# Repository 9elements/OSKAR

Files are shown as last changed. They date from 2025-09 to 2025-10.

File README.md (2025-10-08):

# Open Source Keyboard Appliance powered by Rust

OSKAR is a firmware for the Raspberry Pi Pico it combines the 9elements picoprog project and additional Hid code into a firmware for our multi-feature Makro-Keypad.
## Prerequisites

Before you can compile and use OSKAR, you need to install the following dependencies:

- Rust and Cargo: Follow the instructions on the [official Rust website](https://www.rust-lang.org/tools/install) to install Rust and Cargo.
- Install flip-link and elf2uf2

```sh
# Only Linux
sudo apt install build-essential libudev-dev pkg-config

# All systems
cargo install flip-link elf2uf2-rs
```

## Compiling the Firmware

To compile the firmware, follow these steps:

1. Clone the repository:

```sh
git clone https://github.com/9elements/OSKAR.git
cd OSKAR
```

Build the firmware:

```sh
cargo run --release
```

3. The compiled binary will be located in the `target/thumbv6m-none-eabi/release` directory.

## Flashing the Firmware

To flash the firmware onto the Raspberry Pi Pico, follow these steps:

1. Connect the Raspberry Pi Pico to your computer while holding the BOOTSEL button. This will put the Pico into USB mass storage mode.

2. Copy the UF2 file to the Pico:

```sh
# Linux
cp target/thumbv6m-none-eabi/release/oskar.uf2 /path/to/pi/volume

# macOS
cp target/thumbv6m-none-eabi/release/picoprog.uf2 /Volumes/RPI-RP2/
```

3. The Pico will automatically reboot and start running the new firmware.

## Usage

### Modes

The Device features a 3-position selection switch on its left side. When the switch is moved all the way to the back it simply acts ats the picoprog featuring SPI and UART capabillities (Green LED). Moved all the way to the fromt it acts as Macro Keyboard (Red LED). With the switch in the middle position the device combines Both features at once (purple led).

### Makro Keyboard

The standard firmware of the Keyboard hase the encoder configured as volume knob with mute on press.
The keys 1-3 (from left to right) are configured as o s and f (for open source firmware).

At the top of the file `src/hid.rs` there is a constant struct called ```KEYLAYOUT```.

```rust
const KEYLAYOUT:KeyLayout = KeyLayout {
    encoder_left: KeyType::Media(MediaKey::VolumeDecrement),
    encoder_right: KeyType::Media(MediaKey::VolumeIncrement),
    encoder_button: KeyType::Media(MediaKey::Mute),
    key1: KeyType::Keycode(KeyboardUsage::KeyboardOo),
    key2: KeyType::Keycode(KeyboardUsage::KeyboardSs),
    key3: KeyType::Keycode(KeyboardUsage::KeyboardFf),
};
```

The struct holds the current configuration of the Keyboard, each key can be configured to any keycode of the enum ```KeyType``` located in `src/hid_codes.rs`
for example:

```rust
const KEYLAYOUT:KeyLayout = KeyLayout {
    encoder_left: KeyType::Media(MediaKey::VolumeDecrement),
    encoder_right: KeyType::Media(MediaKey::VolumeIncrement),
    encoder_button: KeyType::Media(MediaKey::Mute),
    key1: KeyType::Keycode(KeyboardUsage::KeyboardF10),
    key2: KeyType::Keycode(KeyboardUsage::KeyboardF11),
    key3: KeyType::Keycode(KeyboardUsage::KeyboardF12),
};
```

Wich could then be used to be configured as hotkeys in your operating system.

### Serial (picocom or combined mode)

Once the firmware is running, you can use any terminal program to communicate with the UART and SPI peripherals via USB. The device will appear as a USB CDC (Communications Device Class) device. Currently `/dev/ttyACM0` (macOS: `/dev/tty.usbmodemOSFC20241`) is a debug console that prints information about the picos current operation.

### UART Communication (picocom or combined mode)

To communicate with the UART peripheral, open the corresponding serial port (e.g., `/dev/ttyACM1` on Linux, `/dev/tty.usbmodemOSFC20243` on macOS) with your terminal program. For now the Baud is fixed at 115200 but can be changed in code. Dynamic reconfiguration is still planned.

### Using Flashrom or Flashprog (picocom or combined mode)

To interact with the Raspberry Pi Pico in for reading and writing SPI flash chips, you can use tools like `flashrom` or `flashprog`. These tools support the `serprog` protocol, which allows communication over a serial interface.

1. Install `flashrom` or `flashprog` e.g.:

```sh
# Debian or Debian-based Linux distributions
sudo apt-get install flashrom

# macOS with Homebrew
brew install flashrom
```

2. Use the following command to read from the SPI flash chip:

```sh
flashrom -p serprog:dev=/dev/ttyACM2 -r backup.bin
```

This command reads the contents of the SPI flash chip and saves it to `backup.bin`.

3. Use the following command to write to the SPI flash chip:

```sh
flashrom -p serprog:dev=/dev/ttyACM2 -w firmware.bin
```

This command writes the contents of `firmware.bin` to the SPI flash chip.

Make sure to replace `/dev/ttyACM2` with the correct serial port if your device is connected to a different port or if you're on a different operating system (on macOS it will be `/dev/tty.usbmodemOSFC20245`).

## License

This project is licensed under the Apache 2.0 License. See the [LICENSE](LICENSE) file for details.

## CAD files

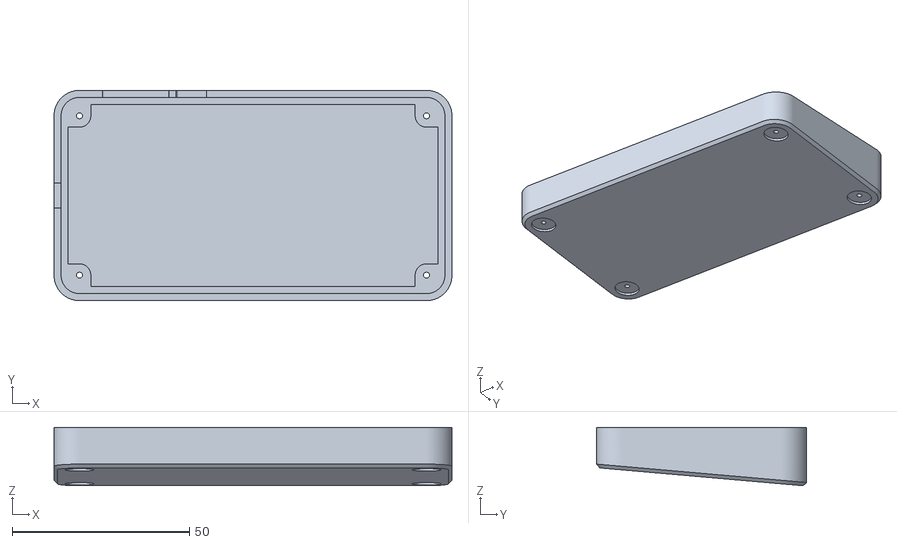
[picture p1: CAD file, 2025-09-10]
hardware/case/CaseBase.stl
112.4 x 59.4 x 16.5

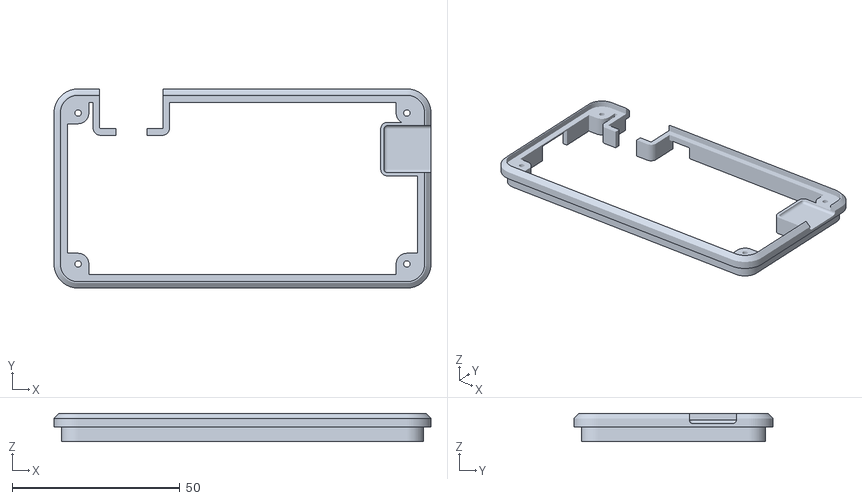
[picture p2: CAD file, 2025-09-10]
hardware/case/CaseTop.stl
112.4 x 59.4 x 8.40

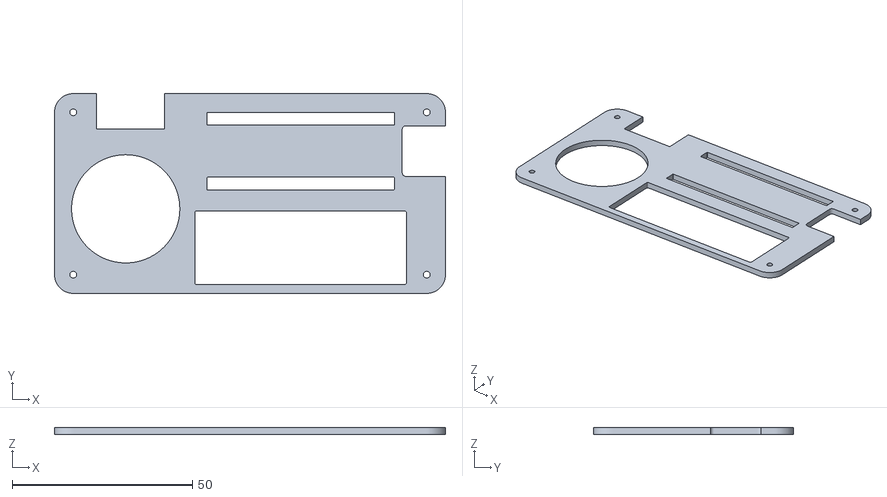
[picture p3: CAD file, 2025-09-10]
hardware/case/TopPlate.stl
108.4 x 55.4 x 2.00

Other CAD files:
hardware/case/TopPlate.dxf

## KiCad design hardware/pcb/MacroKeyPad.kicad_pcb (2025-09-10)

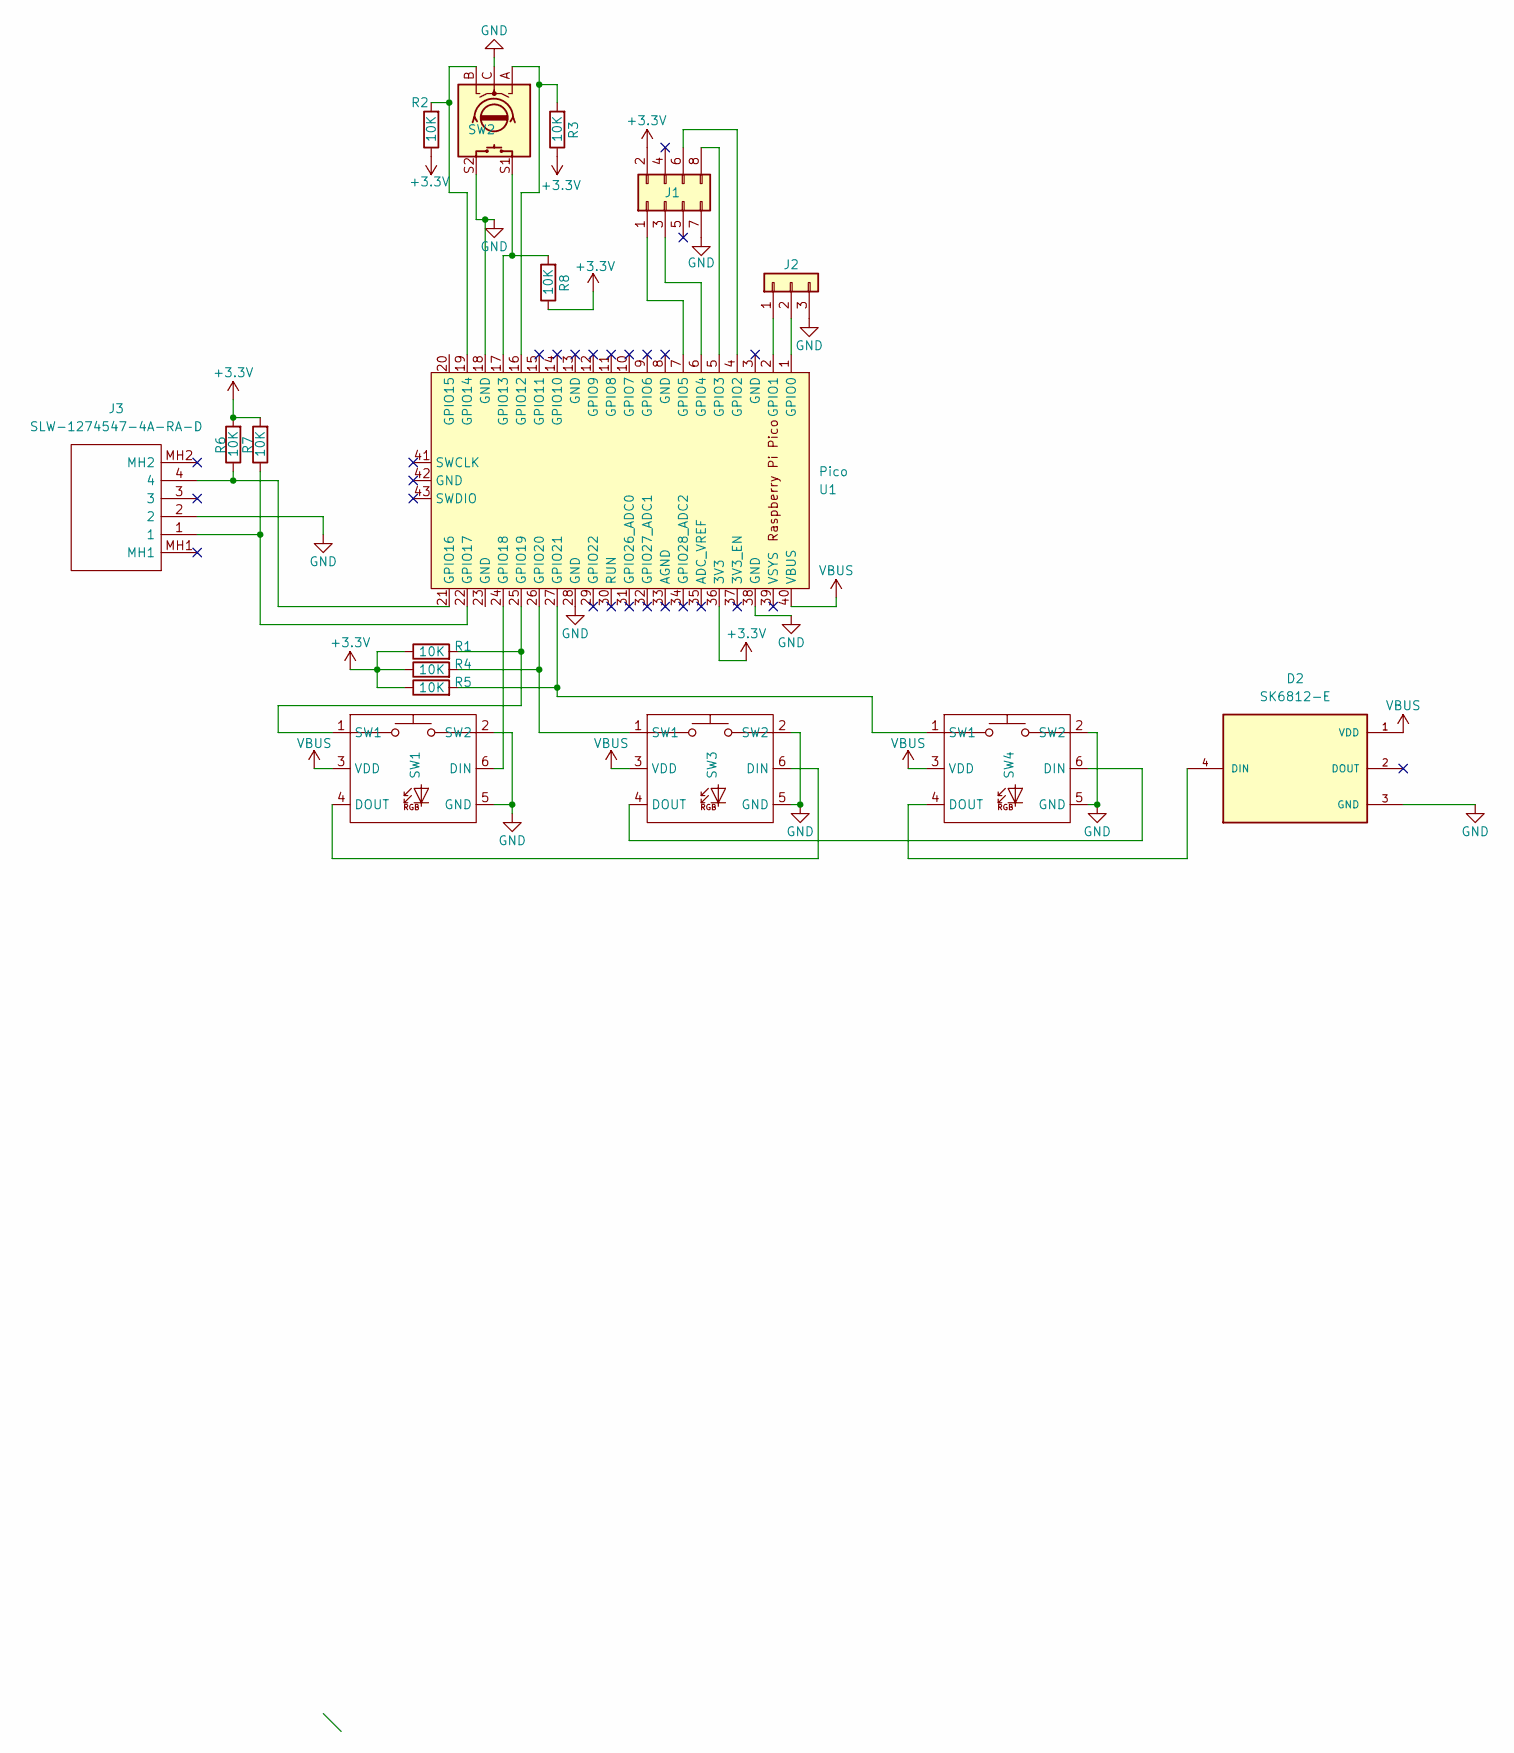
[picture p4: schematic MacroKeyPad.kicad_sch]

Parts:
D2: SK6812-E; LED_SK6812-E; PARTREV 2
J1: Conn_02x04_Odd_Even; IDC-Header_2x04_P2.54mm_Horizontal
J2: Conn_01x03; PinHeader_1x03_P2.54mm_Horizontal
J3: SLW-1274547-4A-RA-D; SLW12745474ARAD; Mouser Part Number 179-SLW12745474ARAD
R1, R2, R3, R4, R5, R6, R7, R8: 10K; R_0805_2012Metric_Pad1.20x1.40mm_HandSolder
SW1, SW3, SW4: Cherry_MX_SK6812_MINI_E
SW2: RotaryEncoder_Switch; RotaryEncoder_Alps_EC11E-Switch_Vertical_H20mm
U1: Pico; RPi_Pico_SMD_HEADER

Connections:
+3.3V: J1.2, R1.1, R2.1, R3.1, R4.1, R5.1, R6.2, R7.2, R8.1, U1.36 (3V3)
GND: D2.3 (GND), J1.7, J2.3, J3.2, SW1.2 (SW2), SW1.5 (GND), SW2.C, SW2.S2, SW3.2 (SW2), SW3.5 (GND), SW4.2 (SW2), SW4.5 (GND), U1.18 (GND), U1.28 (GND), U1.38 (GND)
unnamed: D2.4 (DIN), SW4.4 (DOUT)
unnamed: J1.1, U1.7 (GPIO5)
unnamed: J1.3, U1.6 (GPIO4)
unnamed: J1.6, U1.4 (GPIO2)
unnamed: J1.8, U1.5 (GPIO3)
unnamed: J2.1, U1.2 (GPIO1)
unnamed: J2.2, U1.1 (GPIO0)
unnamed: SW1.6 (DIN), U1.24 (GPIO18)
unnamed: SW1.4 (DOUT), SW3.6 (DIN)
unnamed: R1.2, SW1.1 (SW1), U1.25 (GPIO19)
unnamed: SW3.4 (DOUT), SW4.6 (DIN)
unnamed: R4.2, SW3.1 (SW1), U1.26 (GPIO20)
unnamed: R5.2, SW4.1 (SW1), U1.27 (GPIO21)
unnamed: R3.2, SW2.A, U1.16 (GPIO12)
unnamed: R8.2, SW2.S1, U1.17 (GPIO13)
unnamed: R2.2, SW2.B, U1.19 (GPIO14)
unnamed: J3.4, R6.1, U1.21 (GPIO16)
unnamed: J3.1, R7.1, U1.22 (GPIO17)
VBUS: D2.1 (VDD), SW1.3 (VDD), SW3.3 (VDD), SW4.3 (VDD), U1.40 (VBUS)

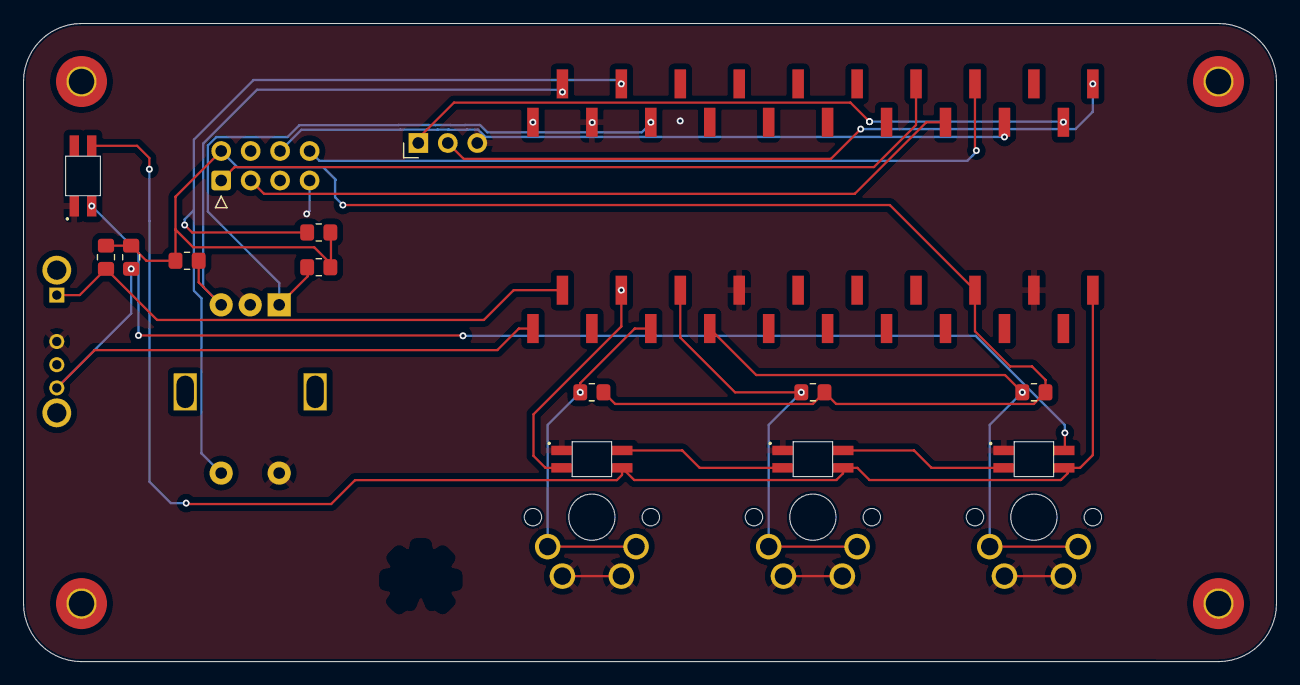
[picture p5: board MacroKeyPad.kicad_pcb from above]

Board: 2 copper layers, 108.0 x 55.0 mm, 17 parts (0 on the bottom side), 21 nets.

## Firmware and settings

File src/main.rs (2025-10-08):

#![no_std]
#![no_main]
#![allow(async_fn_in_trait)]
#![allow(incomplete_features)]
#![feature(impl_trait_in_assoc_type)]
#![feature(type_alias_impl_trait)]

use assign_resources::assign_resources;
use core::panic::PanicInfo;
use cortex_m::peripheral::SCB;
use defmt_rtt as _;
use embassy_executor::Spawner;
use embassy_futures::select::select_array;
use embassy_rp::bind_interrupts;
use embassy_rp::flash::{Async, Flash};
use embassy_rp::gpio::{Input, Level, Output, Pull};
use embassy_rp::peripherals::{self, PIO0, SPI0, USB};
use embassy_rp::pio::InterruptHandler as PIOInterruptHandler;
use embassy_rp::spi::{Config as SpiConfig, Spi};
use embassy_rp::usb::{Driver, InterruptHandler as USBInterruptHandler};
use embassy_rp::watchdog::Watchdog;
use embassy_usb::class::cdc_acm::{CdcAcmClass, State as CdcAcmState};
use embassy_usb::class::hid::{HidReaderWriter, State as Hid_State};
use usbd_hid::descriptor::{KeyboardReport, MediaKeyboardReport, SerializedDescriptor};

use embassy_usb::{Config as UsbConfig, UsbDevice};
use heapless::String;
use static_cell::StaticCell;
use ufmt::uwrite;

mod hid;
mod layouts;
mod led;
mod uart;
bind_interrupts!(struct Irqs {
    USBCTRL_IRQ => USBInterruptHandler<USB>;
    PIO0_IRQ_0 => PIOInterruptHandler<PIO0>;
});

assign_resources! {
    uart: UartResources{
        peripheral: PIO0,
        tx: PIN_0,
        rx: PIN_1,
    }
    spi: SpiResources{
        peripheral: SPI0,
        clk: PIN_2,
        mosi: PIN_3,
        mosi_dma: DMA_CH2,
        miso: PIN_4,
        miso_dma: DMA_CH3,
        cs: PIN_5,
        led: PIN_25,
    }

    hid: ButtonResources{
        key1: PIN_19,
        key2: PIN_20,
        key3: PIN_21,
        encoder_button: PIN_13,
    }

    encoder: EncoderResources{
        encoder_right: PIN_14,
        encoder_left: PIN_12,
    }

    led: LedResources{
        peripheral: PIO1,
        led_gpio: PIN_18,
        led_dma: DMA_CH0,
    }

    selector_switch: ModeSwitchRessources{
        selector_kb: PIN_16,
        selector_picocprog: PIN_17,
    }
}

#[derive(Clone, Copy, Debug)]
pub enum DeviceMode {
    Keyboard,
    Picoprog,
    Universal,
}

// According to Serial Flasher Protocol Specification - version 1
const FLASH_SIZE: usize = 2 * 1024 * 1024;



#[embassy_executor::main]
async fn main(spawner: Spawner) {
    let p: embassy_rp::Peripherals = embassy_rp::init(Default::default());
    let r: AssignedResources = split_resources!(p);
    let driver = Driver::new(p.USB, Irqs);

    let selector_keyboard: Input<'_> = Input::new(r.selector_switch.selector_kb, Pull::Up);
    let selector_picoprog: Input<'_> = Input::new(r.selector_switch.selector_picocprog, Pull::Up);
    let watchdog = Watchdog::new(p.WATCHDOG);

    let mode: DeviceMode = if selector_keyboard.get_level() == Level::Low {
        defmt::info!("keyboard mode");
        DeviceMode::Keyboard
    } else if selector_picoprog.get_level() == Level::Low {
        defmt::info!("picoprog mode");
        DeviceMode::Picoprog
    } else {
        defmt::info!("neutral mode");
        DeviceMode::Universal
    };

    let mut flash = Flash::<_, Async, FLASH_SIZE>::new(p.FLASH, p.DMA_CH4);
    let mut uid: [u8; 8] = [0; 8];
    flash.blocking_unique_id(&mut uid).unwrap_or_default();

    static UID_STR: StaticCell<String<16>> = StaticCell::new();
    let uid_str = UID_STR.init(String::<16>::new());
    for byte in uid.iter() {
        uwrite!(uid_str, "{:02X}", *byte).unwrap_or_default();
    }

    let config = {
        let mut config = UsbConfig::new(0x1ced, 0xc0fe);
        config.manufacturer = Some("9elements");
        config.product = Some("oskar");
        config.serial_number = Some(uid_str.as_str());
        config.max_power = 100;
        config.max_packet_size_0 = 64;

        // Required for windows compatibility.
        // https://developer.nordicsemi.com/nRF_Connect_SDK/doc/1.9.1/kconfig/CONFIG_CDC_ACM_IAD.html#help
        config.device_class = 0xEF;
        config.device_sub_class = 0x02;
        config.device_protocol = 0x01;
        config.composite_with_iads = true;
        config
    };

    let mut builder: embassy_usb::Builder<'_, Driver<'_, USB>> = {
        static CONFIG_DESCRIPTOR: StaticCell<[u8; 256]> = StaticCell::new();
        static BOS_DESCRIPTOR: StaticCell<[u8; 256]> = StaticCell::new();
        static CONTROL_BUF: StaticCell<[u8; 64]> = StaticCell::new();
        static MSOS_DESCRIPTOR: StaticCell <[u8; 256]> = StaticCell::new();

        let builder = embassy_usb::Builder::new(
            driver,
            config,
            CONFIG_DESCRIPTOR.init([0; 256]),
            BOS_DESCRIPTOR.init([0; 256]),
            MSOS_DESCRIPTOR.init([0; 256]), // no msos descriptors
            CONTROL_BUF.init([0; 64]),
        );
        builder
    };

    spawner.spawn(led::led_task(r.led, mode)).unwrap();

    if !(matches!(mode, DeviceMode::Keyboard)) {
        let uart_class = {
            static STATE: StaticCell<CdcAcmState> = StaticCell::new();
            let state = STATE.init(CdcAcmState::new());
            CdcAcmClass::new(&mut builder, state, 64)
        };

        let serprog_class = {
            static STATE: StaticCell<CdcAcmState> = StaticCell::new();
            let state = STATE.init(CdcAcmState::new());
            CdcAcmClass::new(&mut builder, state, 64)
        };

        spawner.spawn(uart::uart_task(uart_class, r.uart)).unwrap();
        spawner.spawn(serprog_task(serprog_class, r.spi)).unwrap();
    }

    if !(matches!(mode, DeviceMode::Picoprog)) {
        let keyboard_class: HidReaderWriter<'_, Driver<'_, USB>, 1, 8> = {
            static STATE: StaticCell<Hid_State> = StaticCell::new();
            let state = STATE.init(Hid_State::new());

            let config = embassy_usb::class::hid::Config {
                report_descriptor: KeyboardReport::desc(),
                request_handler: None,
                poll_ms: 60,
                max_packet_size: 64,
            };

            HidReaderWriter::new(&mut builder, state, config)
        };

        let multimedia_class: HidReaderWriter<'_, Driver<'_, USB>, 1, 8> = {
            static STATE: StaticCell<Hid_State> = StaticCell::new();
            let state = STATE.init(Hid_State::new());

            let config = embassy_usb::class::hid::Config {
                report_descriptor: MediaKeyboardReport::desc(),
                request_handler: None,
                poll_ms: 60,
                max_packet_size: 64,
            };

            HidReaderWriter::new(&mut builder, state, config)
        };

        spawner.spawn(hid::hid_task(spawner, keyboard_class, multimedia_class, r.hid, r.encoder)).unwrap();
    }

    let usb = builder.build();
    // We can't really recover here so just unwrap
    spawner.spawn(usb_task(usb)).unwrap();
    spawner
        .spawn(selector_watchdog_task(
            watchdog,
            selector_keyboard,
            selector_picoprog,
        ))
        .unwrap();

    loop {
        embassy_time::Timer::after(embassy_time::Duration::from_secs(1)).await;
    }
}

type CustomUsbDriver = Driver<'static, USB>;
type CustomUsbDevice = UsbDevice<'static, CustomUsbDriver>;

#[embassy_executor::task]
async fn usb_task(mut usb: CustomUsbDevice) -> ! {
    usb.run().await
}

#[embassy_executor::task]
async fn selector_watchdog_task(
    mut watchdog: Watchdog,
    mut selector_keyboard: Input<'static>,
    mut selector_picoprog: Input<'static>,
) {
    let (_, _) = select_array([
        selector_keyboard.wait_for_any_edge(),
        selector_picoprog.wait_for_any_edge(),
    ])
    .await;

    watchdog.trigger_reset();
}

#[embassy_executor::task]
async fn serprog_task(class: CdcAcmClass<'static, CustomUsbDriver>, r: SpiResources) -> ! {
    let mut config = SpiConfig::default();
    config.frequency = 12_000_000; // 12 MHz

    let spi = Spi::new(
        r.peripheral,
        r.clk,
        r.mosi,
        r.miso,
        r.mosi_dma,
        r.miso_dma,
        config,
    );
    let cs = Output::new(r.cs, Level::High);
    let led = Output::new(r.led, Level::Low);

    let set_freq_cb = move |spi: &mut Spi<'_, SPI0, embassy_rp::spi::Async>, freq| {
        spi.set_frequency(freq);
    };

    let serprog = serprog::Serprog::new(spi, cs, led, class, Some(set_freq_cb));
    serprog.run_loop().await
}

#[panic_handler]
fn panic(info: &PanicInfo) -> ! {
    // Print out the panic info
    log::error!("Panic occurred: {:?}", info);

    // Reboot the system
    SCB::sys_reset();
}

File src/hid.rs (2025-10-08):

use crate::{EncoderResources, ButtonResources};
use crate::layouts::{KeyLayout};
use defmt::unreachable;
use defmt_rtt as _;
use embassy_executor::{InterruptExecutor, Spawner};
use embassy_futures::select::select_array;
use embassy_rp::gpio::{Input, Level, Pull};
use embassy_rp::interrupt;
use embassy_rp::interrupt::{InterruptExt, Priority};
use embassy_rp::peripherals::USB;
use embassy_rp::usb::Driver;
use embassy_usb::class::hid::HidReaderWriter;
use usbd_hid::descriptor::*;
use embassy_sync::pubsub::PubSubChannel;
use embassy_sync::blocking_mutex::raw::CriticalSectionRawMutex;
type CustomHid = HidReaderWriter<'static, Driver<'static, USB>, 1, 8>;
static KEY_EVENT_QUEUE: PubSubChannel::<CriticalSectionRawMutex, KeyEvent, 2, 2, 2> = PubSubChannel::new();

#[derive(Clone)]
#[derive(PartialEq)]
enum Key {
    EncoderLeft,
    EncoderRight,
    EncoderButton,
    Key1,
    Key2,
    Key3,
}

#[derive(Clone)]
#[derive(PartialEq)]
enum Event {
    Pressed,
    Released,
}
#[derive(Clone)]
struct KeyEvent {
    key: Key,
    event: Event,
}

pub enum KeyType {
    Media(MediaKey),
    Keycode(KeyboardUsage),
}

const KEYLAYOUT:KeyLayout = KeyLayout {
    encoder_left: KeyType::Media(MediaKey::VolumeDecrement),
    encoder_right: KeyType::Media(MediaKey::VolumeIncrement),
    encoder_button: KeyType::Media(MediaKey::Mute),
    key1: KeyType::Keycode(KeyboardUsage::KeyboardOo),
    key2: KeyType::Keycode(KeyboardUsage::KeyboardSs),
    key3: KeyType::Keycode(KeyboardUsage::KeyboardFf),
};

#[embassy_executor::task]
pub async fn hid_task(spawner: Spawner, mut keyboard_class: CustomHid, mut multimedia_class: CustomHid, button_resources: ButtonResources, encoder_resources: EncoderResources) -> ! {

    interrupt::SWI_IRQ_0.set_priority(Priority::P2);
    let spawner_encoder: embassy_executor::SendSpawner = EXECUTOR_ENCODER.start(interrupt::SWI_IRQ_0);
    spawner_encoder.spawn(encoder_task(encoder_resources)).unwrap();

    spawner.spawn(button_task(button_resources)).unwrap();

    let mut sub = KEY_EVENT_QUEUE.subscriber().unwrap();

    loop {
        let key_event: KeyEvent = sub.next_message_pure().await;

        match key_event.key {
            Key::EncoderLeft => {
                (keyboard_class, multimedia_class) = handle_encoder_interaction(keyboard_class, multimedia_class, KEYLAYOUT.encoder_left).await;
            },
            Key::EncoderRight => {
                (keyboard_class, multimedia_class) = handle_encoder_interaction(keyboard_class, multimedia_class, KEYLAYOUT.encoder_right).await;
            },
            Key::EncoderButton => {
                (keyboard_class, multimedia_class) = send_code(keyboard_class, multimedia_class, KEYLAYOUT.encoder_button, key_event.event).await;
            },
            Key::Key1 => {
                (keyboard_class, multimedia_class) = send_code(keyboard_class, multimedia_class, KEYLAYOUT.key1, key_event.event).await;
            },
            Key::Key2 => {
                (keyboard_class, multimedia_class) = send_code(keyboard_class, multimedia_class, KEYLAYOUT.key2, key_event.event).await;
            },
            Key::Key3 => {
                (keyboard_class, multimedia_class) = send_code(keyboard_class, multimedia_class, KEYLAYOUT.key3,key_event.event).await;
            }
        }
    }
}


static EXECUTOR_ENCODER: InterruptExecutor = InterruptExecutor::new();

#[interrupt]
unsafe fn SWI_IRQ_0() {
    unsafe { EXECUTOR_ENCODER.on_interrupt() }
}

#[embassy_executor::task]
pub async fn encoder_task(r: EncoderResources) -> ! {

    let encoder_left: Input<'_> = Input::new(r.encoder_left, Pull::None);

    let mut encoder_right: Input<'_> = Input::new(r.encoder_right, Pull::None);

    let publisher = KEY_EVENT_QUEUE.publisher().unwrap();

    loop {
        encoder_right.wait_for_falling_edge().await;

        if encoder_left.get_level() == Level::Low {
            publisher.publish_immediate(KeyEvent {key: Key::EncoderLeft, event: Event::Pressed});
        } else {
            publisher.publish_immediate(KeyEvent {key: Key::EncoderRight, event: Event::Pressed});
        };

        encoder_right.wait_for_rising_edge().await;
    }
}

#[embassy_executor::task]
pub async fn button_task(r: ButtonResources) -> ! {

    let mut key1: Input<'_> = Input::new(r.key1, Pull::Up);
    key1.set_schmitt(true);

    let mut key2: Input<'_> = Input::new(r.key2, Pull::Up);
    key2.set_schmitt(true);

    let mut key3: Input<'_> = Input::new(r.key3, Pull::Up);
    key3.set_schmitt(true);

    let mut encoder_button: Input<'_> = Input::new(r.encoder_button, Pull::Up);
    encoder_button.set_schmitt(true);

    let publisher = KEY_EVENT_QUEUE.publisher().unwrap();

    loop {

        let (_, index) = select_array([
            key1.wait_for_any_edge(),
            key2.wait_for_any_edge(),
            key3.wait_for_any_edge(),
            encoder_button.wait_for_any_edge(),
        ])
        .await;

        match index {
            0 => {
                match key1.get_level() {
                    Level::Low => publisher.publish_immediate(KeyEvent {key: Key::Key1, event: Event::Pressed}),
                    Level::High => publisher.publish_immediate(KeyEvent {key: Key::Key1, event: Event::Released}),
                }
            }
            1 => {
                match key2.get_level() {
                    Level::Low => publisher.publish_immediate(KeyEvent {key: Key::Key2, event: Event::Pressed}),
                    Level::High => publisher.publish_immediate(KeyEvent {key: Key::Key2, event: Event::Released}),
                }
            }
            2 => {
                match key3.get_level() {
                    Level::Low => publisher.publish_immediate(KeyEvent {key: Key::Key3, event: Event::Pressed}),
                    Level::High => publisher.publish_immediate(KeyEvent {key: Key::Key3, event: Event::Released}),
                }
            }
            3 => {
                match encoder_button.get_level() {
                    Level::Low => publisher.publish_immediate(KeyEvent {key: Key::EncoderButton, event: Event::Pressed}),
                    Level::High => publisher.publish_immediate(KeyEvent {key: Key::EncoderButton, event: Event::Released}),
                }
            }
            _ => unreachable!(),
        };
    }
}
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

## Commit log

2025-08-13 implement interrupt based task
2025-09-10 add pcb project
    [MacroKeyPad-B_Cu.gbr, MacroKeyPad-B_Mask.gbr, MacroKeyPad-B_Paste.gbr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]
2025-09-10 add case
    [CaseBase.stl, CaseTop.stl, TopPlate.dxf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]
2025-10-08 rework for windows compatabillity
    [hid.rs, main.rs]
